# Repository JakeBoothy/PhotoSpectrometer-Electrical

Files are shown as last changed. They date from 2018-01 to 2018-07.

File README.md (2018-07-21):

# PhotoSpectrometer-Electrical
PCB Design for my visible photospectrometer.

## Version 1

Version 1 was completed for a class project. It performed reasonably well but had a mistake and left out some much needed features. The files are here for reference but it is not recommended that you build it.

## Version 2

I am working on version 2 right now. There is more info on my website but I am cleaning up the design and adding some more features.

* Peltier drivers
* Better amplifier design
* Change microcontroller to STM32
* TFT Screen and encoder
* External ADC
* SD Card
* And much more!

Additionally I am going to do a full optical design with raytracing software and a full mechanical redesign. 

Design was done in eagle.

More info on my blog

https://jakehasahobby.wordpress.com/2017/12/03/electrical-design/
https://jakehasahobby.wordpress.com/2018/07/18/plan-new-features/

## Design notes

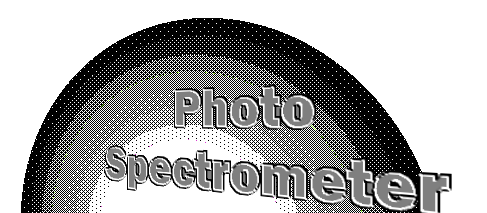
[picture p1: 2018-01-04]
V2/Eagle/godawful.bmp

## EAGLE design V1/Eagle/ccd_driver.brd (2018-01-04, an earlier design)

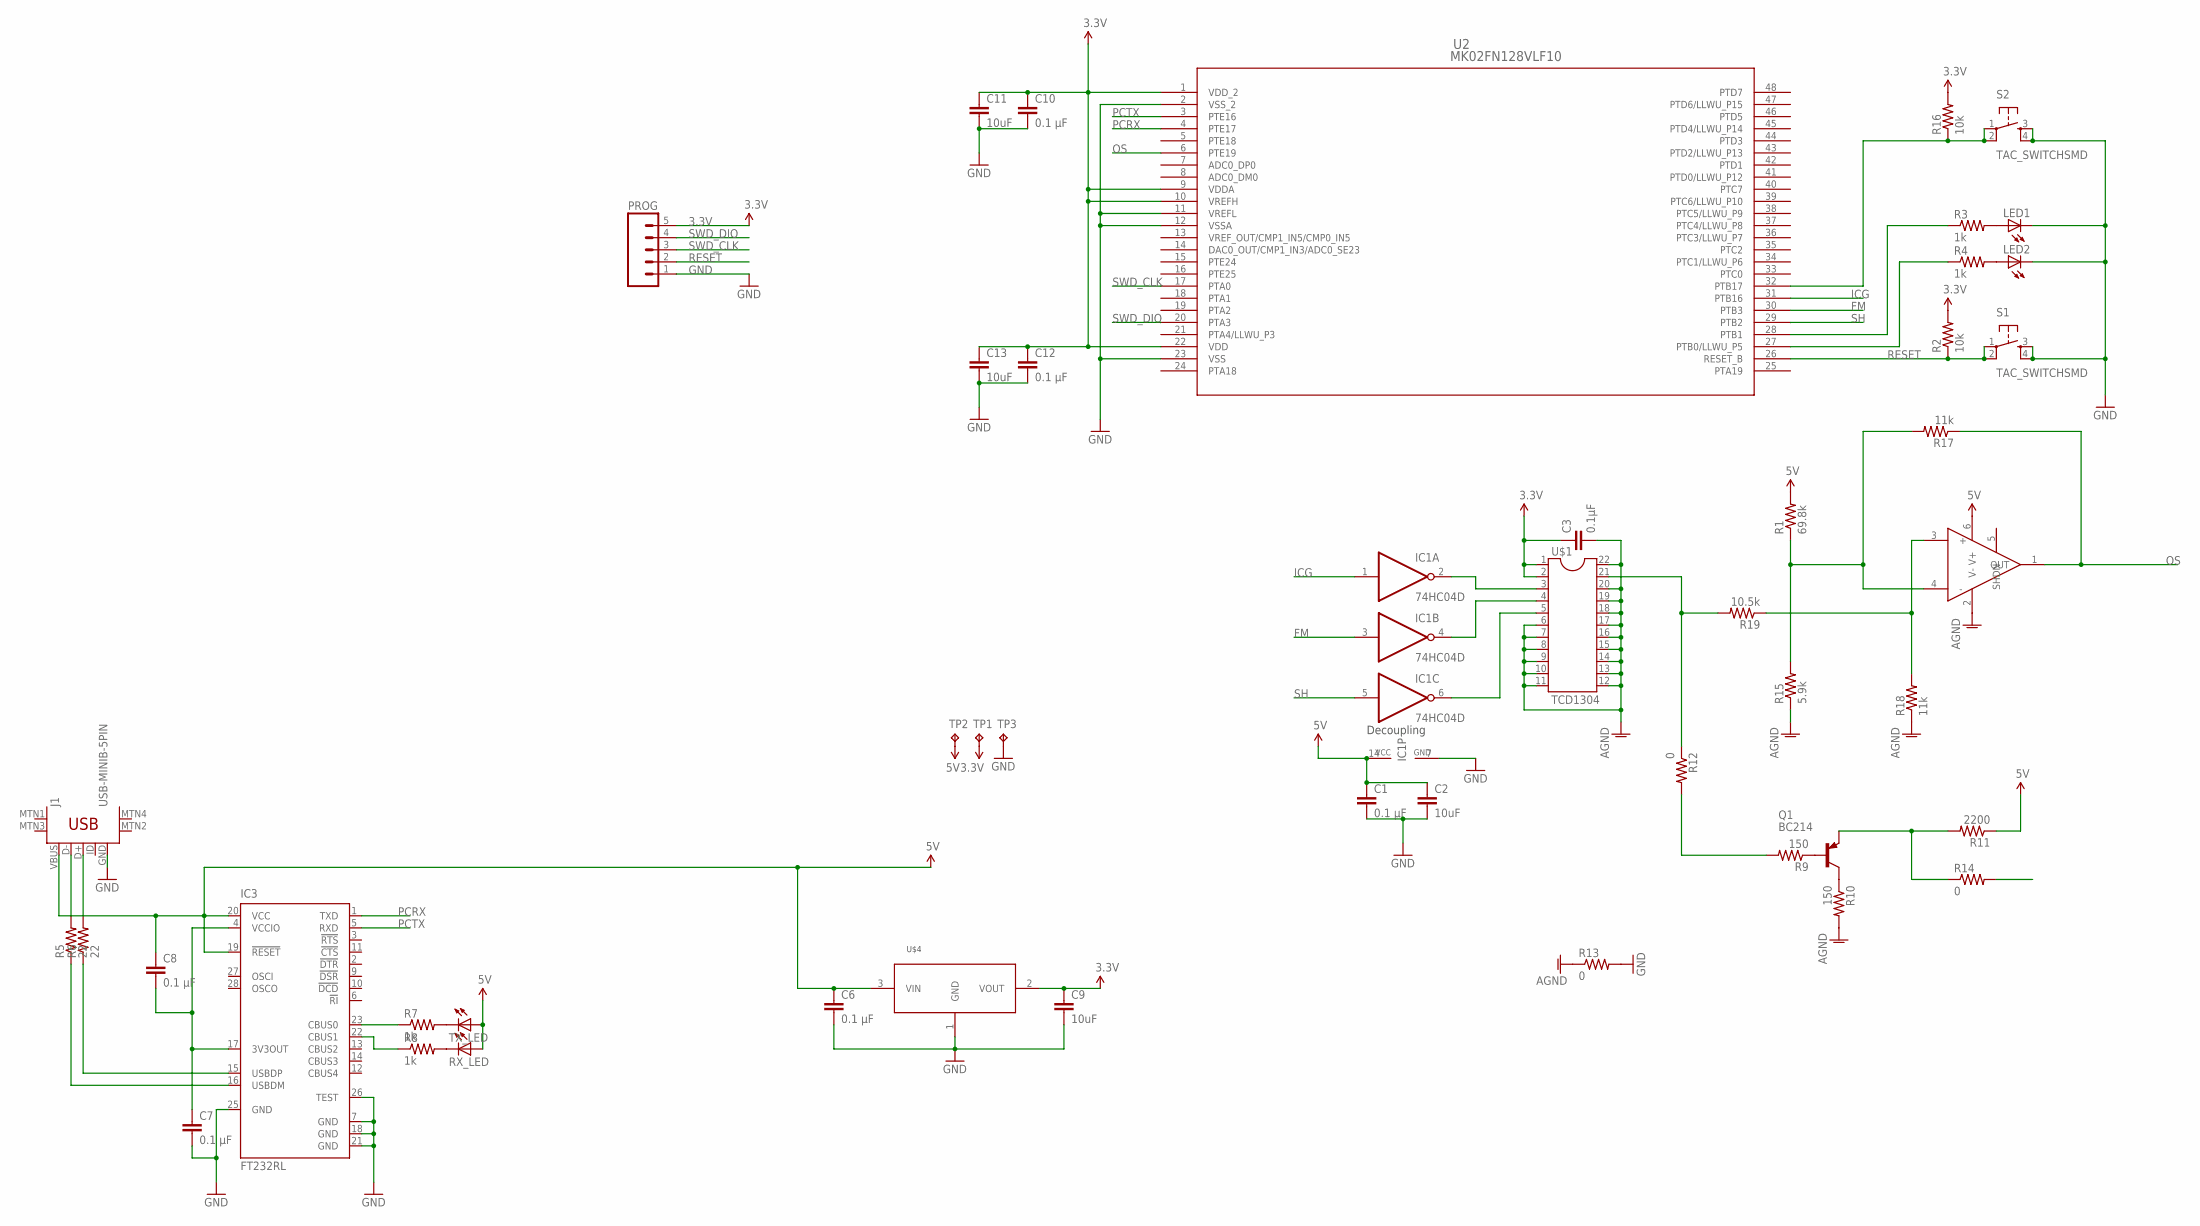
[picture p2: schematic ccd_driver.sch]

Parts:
C1, C6, C7, C8, C10, C12: 0.1 µF; C1206
C2, C9, C11, C13: 10uF; C1206
C3: 0.1µF; C1206
IC1: 74HC04D; SO14
IC3: FT232RL; SSOP28
J1: USB-MINIB-5PIN; USB-MINIB
LED1, LED2: LEDCHIPLED_0805; CHIPLED_0805
PROG: M05LOCK; 1X05_LOCK
Q1: BC214; TO92
R1: 69.8k; R0805
R2, R16: 10k; R0805
R3, R4, R7, R8: 1k; R0805
R5, R6: 22; R0805
R9, R10: 150; R0805
R11: 2200; R0805
R12, R13, R14: 0; R0805
R15: 5.9k; R0805
R17, R18: 11k; R0805
R19: 10.5k; R0805
RX_LED: LEDCHIPLED_0805; CHIPLED_0805
S1, S2: TAC_SWITCHSMD; TACTILE-SWITCH-SMD
TP1, TP2, TP3: TPPAD1-17Y; P1-17Y
TX_LED: LEDCHIPLED_0805; CHIPLED_0805
U2: MK02FN128VLF10; LQFP-48_7X7X1.6
U$1: TCD1304
U$3: LTC6252; TSOT23-6
U$4: LD1117V33; TO220H

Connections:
3.3V: C3.1, C9.1, C10.1, C11.1, C12.1, C13.1, PROG.5, R2.2, R16.2, TP1.TP, U2.1 (VDD_2), U2.9 (VDDA), U2.10 (VREFH), U2.22 (VDD), U$1.1, U$1.2, U$4.2 (VOUT)
5V: C1.1, C2.1, C6.1, C8.1, IC1.14 (VCC), IC3.19 (!RESET), IC3.20 (VCC), J1.VBUS, R1.2, R11.1, RX_LED.A, TP2.TP, TX_LED.A, U$3.6 (V+), U$4.3 (VIN)
AGND: C3.2, R10.2, R13.1, R15.1, R18.1, U$1.6, U$1.7, U$1.8, U$1.9, U$1.10, U$1.11, U$1.12, U$1.13, U$1.14, U$1.15, U$1.16, U$1.17, U$1.18, U$1.19, U$1.20, U$1.22, U$3.2 (V-)
BU: Q1.1 (E), R11.2, R14.1
FM: IC1.3 (I), U2.30 (PTB3)
GND: C1.2, C2.2, C6.2, C7.2, C9.2, C10.2, C11.2, C12.2, C13.2, IC1.7 (GND), IC3.7 (GND), IC3.18 (GND), IC3.21 (GND), IC3.25 (GND), IC3.26 (TEST), J1.GND, LED1.C, LED2.C, PROG.1, R13.2, S1.3, S1.4, S2.3, S2.4, TP3.TP, U2.2 (VSS_2), U2.11 (VREFL), U2.12 (VSSA), U2.23 (VSS), U$4.1 (GND)
ICG: IC1.1 (I), U2.31 (PTB16)
unnamed: R18.2, R19.1, U$3.3 (+)
unnamed: IC1.2 (O), U$1.3
unnamed: IC1.4 (O), U$1.4
unnamed: IC1.6 (O), U$1.5
unnamed: Q1.2 (B), R9.1
unnamed: R16.1, S2.1, S2.2, U2.32 (PTB17)
unnamed: R1.1, R15.2, R17.2, U$3.4 (-)
unnamed: Q1.3 (C), R10.1
unnamed: R12.1, R19.2, U$1.21
unnamed: R3.1, U2.28 (PTB1)
unnamed: LED1.A, R3.2
unnamed: LED2.A, R4.2
unnamed: J1.D-, R5.2
unnamed: R4.1, U2.27 (PTB0/LLWU_P5)
unnamed: J1.D+, R6.2
unnamed: C7.1, C8.2, IC3.4 (VCCIO), IC3.17 (3V3OUT)
unnamed: IC3.23 (CBUS0), R7.1
unnamed: IC3.16 (USBDM), R5.1
unnamed: IC3.15 (USBDP), R6.1
unnamed: IC3.22 (CBUS1), R8.1
unnamed: R8.2, RX_LED.C
unnamed: R7.2, TX_LED.C
unnamed: R9.2, R12.2
OS: R14.2, R17.1, U2.6 (PTE19), U$3.1 (OUT)
PCRX: IC3.1 (TXD), U2.4 (PTE17)
PCTX: IC3.5 (RXD), U2.3 (PTE16)
RESET: PROG.2, R2.1, S1.1, S1.2, U2.26 (RESET_B)
SH: IC1.5 (I), U2.29 (PTB2)
SWD_CLK: PROG.3, U2.17 (PTA0)
SWD_DIO: PROG.4, U2.20 (PTA3)

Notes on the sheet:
Decoupling

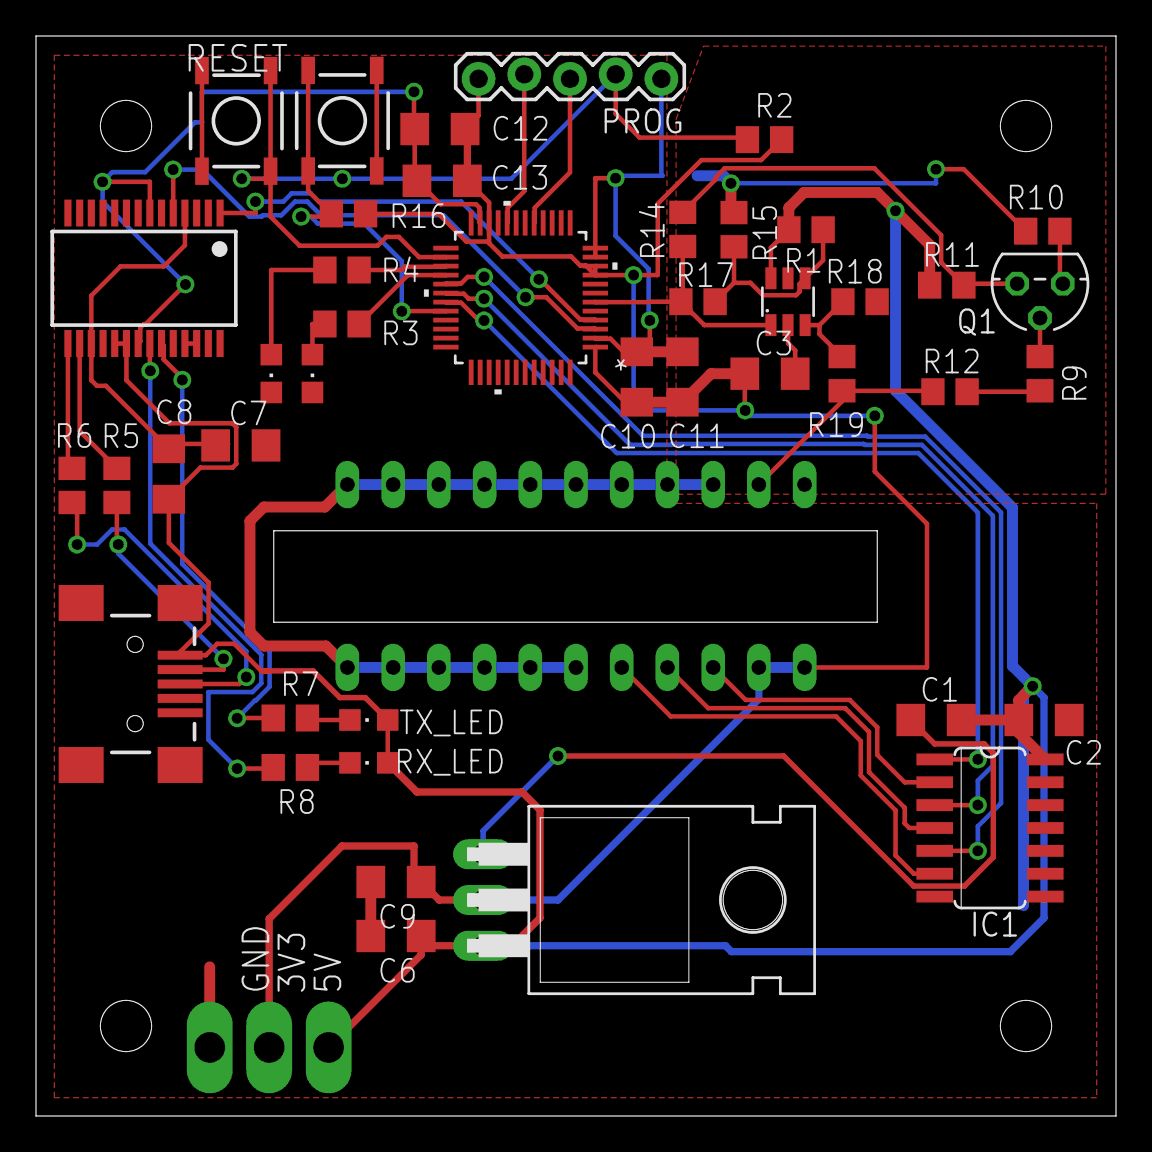
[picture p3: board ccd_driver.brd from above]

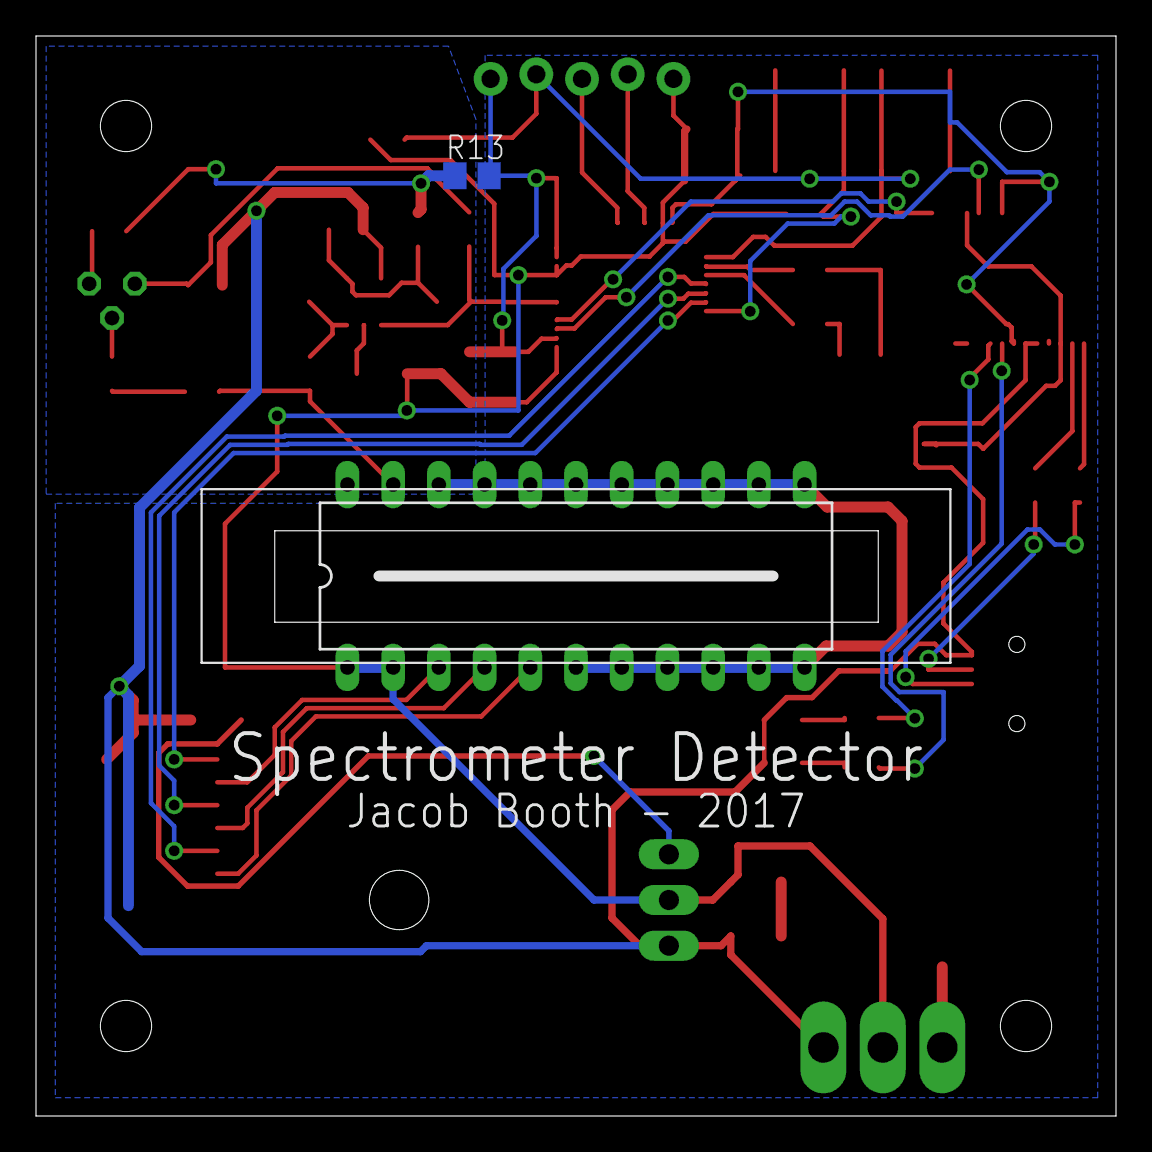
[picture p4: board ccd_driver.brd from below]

Board: 2 copper layers, 60.0 x 60.0 mm, 48 parts (2 on the bottom side), 37 nets.

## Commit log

2018-01-04 init commit
    [ccd_driver.brd, ccd_driver.sch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]
2018-07-13 Added new version, v1 and v2
    [ccd_driver.brd, ccd_driver.sch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]
2018-07-13 Changed fM,SH,ICG pins to match with timers, added TODO list, cleaned up schematics and add them to different sheets
    [ccd_driver.brd, ccd_driver.sch]
2018-07-13 added micro sd card
    [ccd_driver.sch]
2018-07-18 added peltier driver: MOSFET w/ LPF, 12V 5A
    [ccd_driver.sch]
2018-07-18 added LTSpice sch for pelt driver
    [ccd_driver.sch]
2018-07-18 added 36V tolerant buck reg -> 3.3V 3A
    [ccd_driver.sch]
2018-07-19 added fan mosfet control
    [ccd_driver.sch]
2018-07-19 added different USB controller, micro usb, input protection
    [ccd_driver.sch]
2018-07-19 removed old .brd file
    [ccd_driver.brd]
2018-07-19 added thermistors
    [ccd_driver.sch, thermistorEquations.xlsx]
2018-07-19 changed jst fan connector
    [ccd_driver.sch]
2018-07-21 added TFT screen + encoder, small cleanup, doubled peltier driver
    [ccd_driver.sch]
2018-07-21 added my name to sch
    [ccd_driver.sch]
2018-07-21 minor cleanup
    [ccd_driver.sch]
2018-07-25 added precision voltage reference
2018-07-28 added current sense circuit for peltier drivers
    [ccd_driver.sch]
2018-07-28 added notes on current sense
    [ccd_driver.sch]
2018-07-28 added voltage sense, current sense might be useless
    [ccd_driver.sch]
2018-07-28 minor changes
    [ccd_driver.sch]
2018-07-28 changed most caps and resistors to 0603
    [ccd_driver.sch]
2018-07-28 fixed fan circuit
    [ccd_driver.sch]
2018-07-28 removed current sense because its not very smart
    [ccd_driver.sch]
2018-07-28 added external ADC, need to finish circuit
2018-09-03 overhauled power subsection. Changed LC values for lpfs. Minor changes, added sim for output
    [ccd_driver.sch]
2018-10-20 modified power supply again. Added filter, ldo, and charge pump for analog rails. Created new schematic frame. General organization and minor changes
    [ccd_driver.sch]
2018-10-20 made matlab script to autocalculate amplifier resistor values
    [ccd_driver.sch]
2018-10-20 added new amp circuit for CCD
    [ccd_driver.sch]
2018-10-21 added filtering to analog section
    [ccd_driver.sch]

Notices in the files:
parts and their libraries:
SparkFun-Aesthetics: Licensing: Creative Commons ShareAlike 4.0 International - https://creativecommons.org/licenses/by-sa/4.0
